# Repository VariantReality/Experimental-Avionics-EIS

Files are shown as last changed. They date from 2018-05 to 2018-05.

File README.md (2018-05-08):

# Experimental-Avionics-EIS

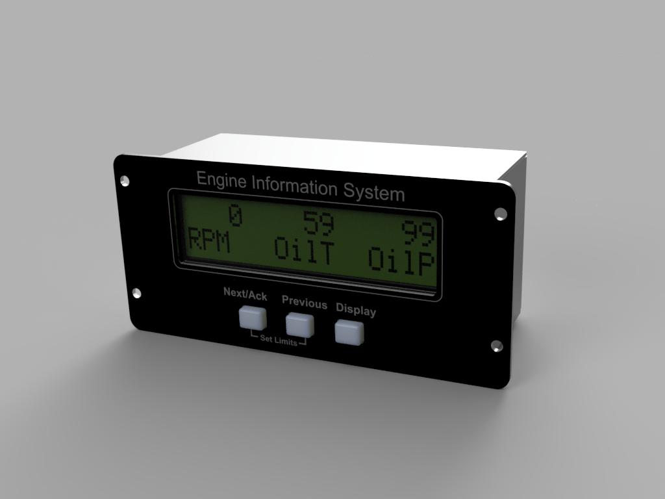
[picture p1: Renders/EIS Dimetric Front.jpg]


## Contact Information
https://hackaday.io/jomega

## Description
In an effort to bring homebuilt avionics to the experimental aircraft community, I have created a set of plans for a homebuilt aircraft engine monitor.  The processor system is based on the same technology found in the Arduino board, allowing the builder to easily add custom firmware. All of the mechanical parts can be sent to hobbyist-friendly fabrication services at reasonable costs or built at home. Since the mechanical dimensions are provided, the builder can also design a custom case. 

The features of the engine monitor include:

- EGT (x6)
- CHT (x6)
- Oil Temperature
- Oil Pressure
- Coolant Temperature
- Carb Temperature
- Outside Air Temperature (OAT)
- Tachometer input (x2) (configurable for both inductive and open/collector)
- Fuel flow (x2 for supply/return)
- 6 analog auxiliary inputs
- Flight timer
- Tach time
- Serial data output
- Backlight brightness control
- Warning light with configurable limits
- User definable pages (x4)
- Onboard memory

This repository includes all of the information you need to build the EIS yourself including:

 - Schematics
 - Mechanical CAD files
 - Firmware source code
 - Bill of Materials

The cost to buy the components and fabricate the enclosure comes to approximately $250 if you use the recommended vendors.

## Required Tools

### Software:
- Autodesk Fusion 360 (Free Enthusiast license)
- Altium Circuit maker
- Front Panel Designer
- Inkscape
- Atmel Studio

### Hardware:
- Waveshare AVR programmer or Atmel ICE programmer (most other programmer options do not work correctly with the ATMega 2560)
- RS-232 to USB converter
- Hakko soldering iron
- Sparkfun hot air gun
- AMScope
- Soldering vise + base
- Multimeter
- Tweezers
- Solder
- Solder wick
- Flux

## Recommended vendors
- [Front panel express](https://www.frontpanelexpress.com/) (CNC and digital printing)
- [Par-metal](http://www.par-metal.com/) (Sheet metal work)
- [Shapeways](https://www.shapeways.com/) (3D printing)
- [Digikey](https://www.digikey.com/) (Electronic components)

## Construction Steps

1. Modify the faceplate graphic as desired and then order all of the parts listed above
2. When the buttons and button guide arrive, they will require some cleanup. This can be done by sanding the edges where they touch the button guide or by forcing them into the button guide and then repeatedly cycling them back and forth.
3. Assemble the PCB. I would highly recommend doing this in stages and verifying functionality after each stage.
     1. Power supply circuit (verify power LED turns on)
     2. ATMega2560 circuit (verify that Atmel Studio can query the ATMega's ID)
     3. Warning light (verify that the ATMega can toggle the warning light)
     4. DSub connectors
     5. RS-232 circuit (verify that the ATMega can send data to a computer)
     6. FRAM circuit (verify that the flash IC info can be queried)
     7. ADC circuit (verify that the ADC correctly reads the input voltage)
     8. Amplifier/multiplexer circuit (verify that the ADC measures different values when the multiplexer is changed)
     9. Tach/fuel flow circuits (verify that an interrupt is triggered when a voltage is applied to the tach pins)
     10. Button board (verify that the ATMega can read each button)
     11. LCD Screen (verify that the ATMega can print to the display)
4. Assemble the button PCB
5. Program the ATMega with the EIS firmware
6. Place the button guide and buttons in place on the front panel. Place the button PCB on top and use two 4-40 locknuts to secure it in place
7. Attach the LCD to the front panel using  four 4-40 by 1.5" standoffs threaded on one side. 
8. Place the engine monitor board on top of the standoffs and secure with two 4-40 by 7/32 standoffs on the bottom and two 4-40 screw on the top.
9. Place the rear enclosure over the top (it should be a snug fit). Secure using two 4-40 screws.

## Additional Photos



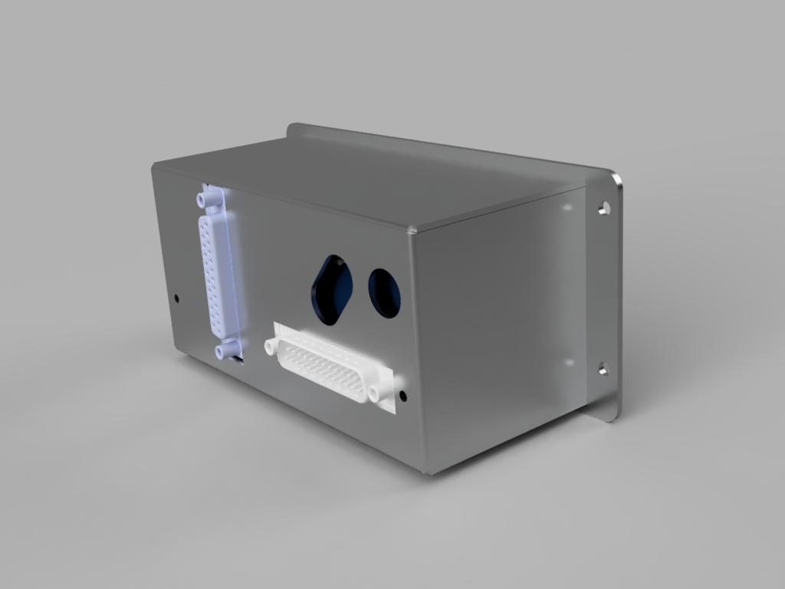
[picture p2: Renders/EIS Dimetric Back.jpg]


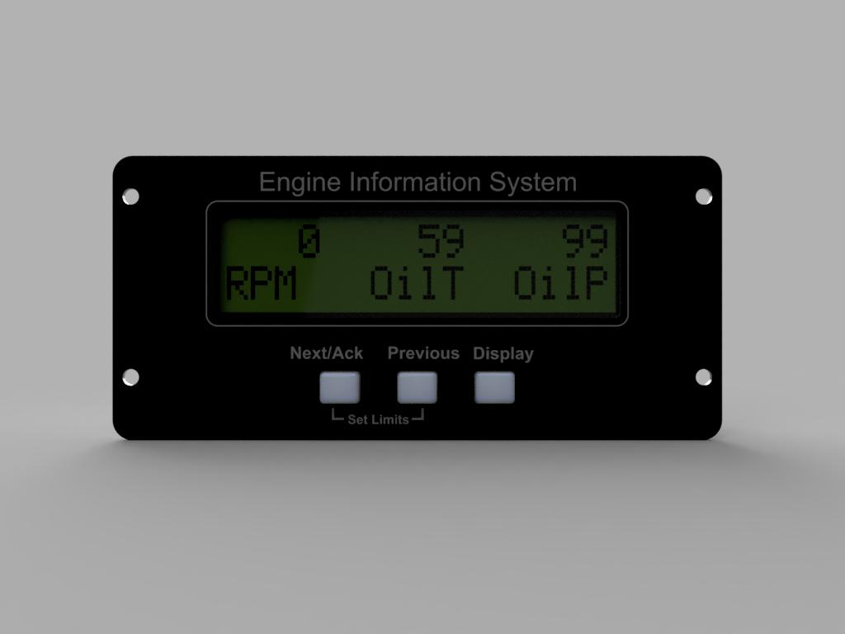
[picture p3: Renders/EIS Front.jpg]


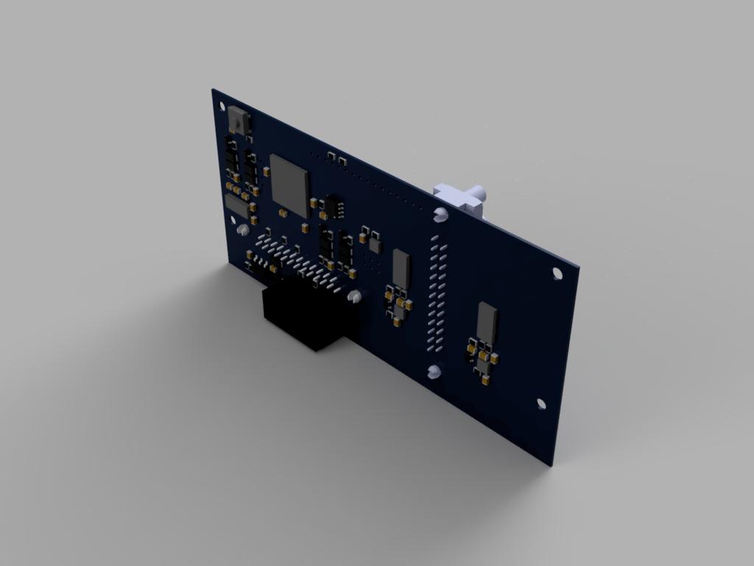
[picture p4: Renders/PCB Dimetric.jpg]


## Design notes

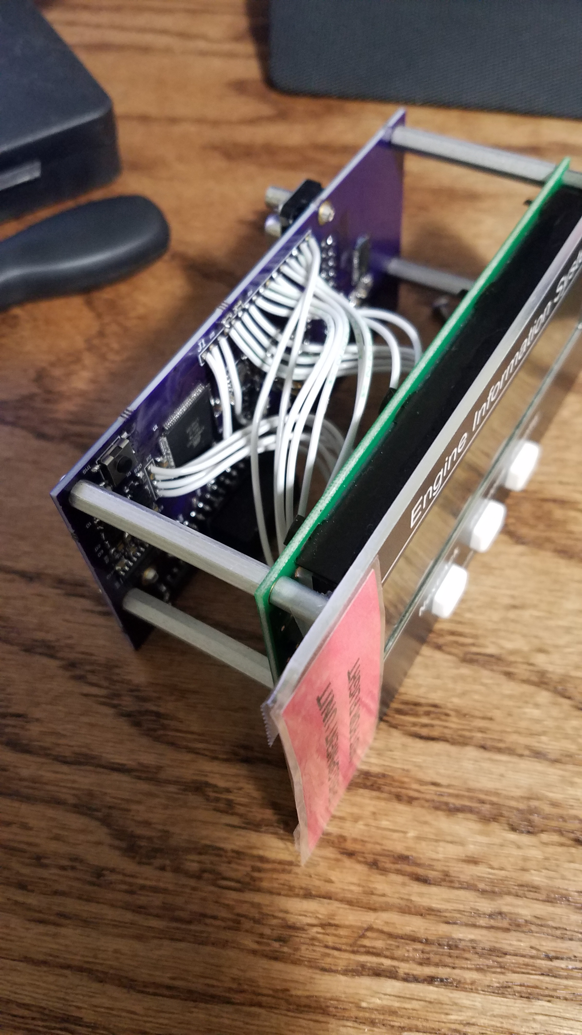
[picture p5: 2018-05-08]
Photos/Inside.jpg

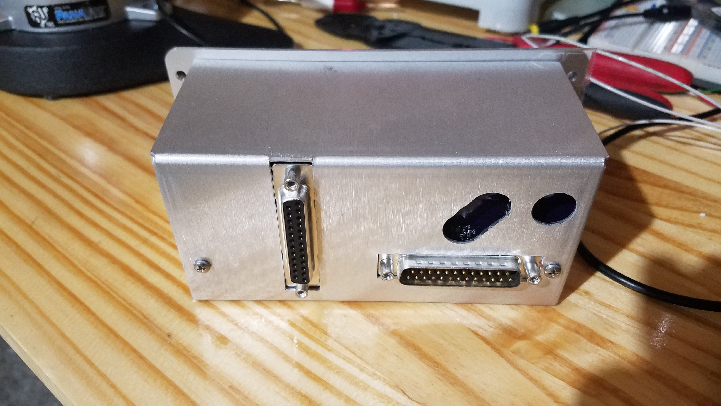
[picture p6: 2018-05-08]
Photos/Back.jpg

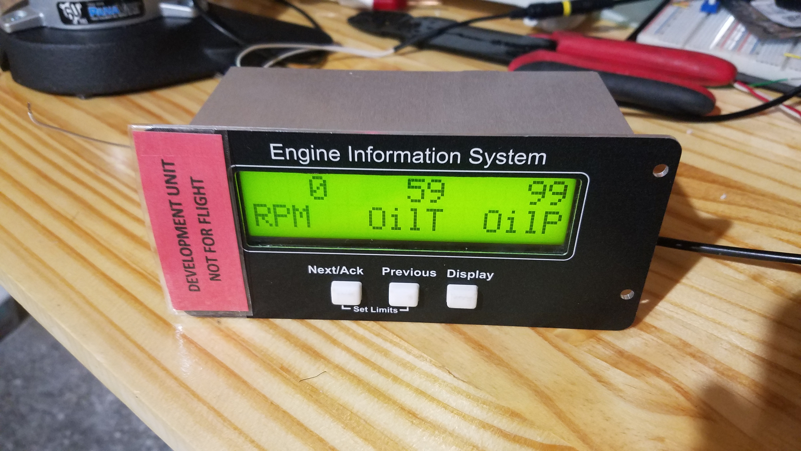
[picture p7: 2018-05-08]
Photos/Front.jpg

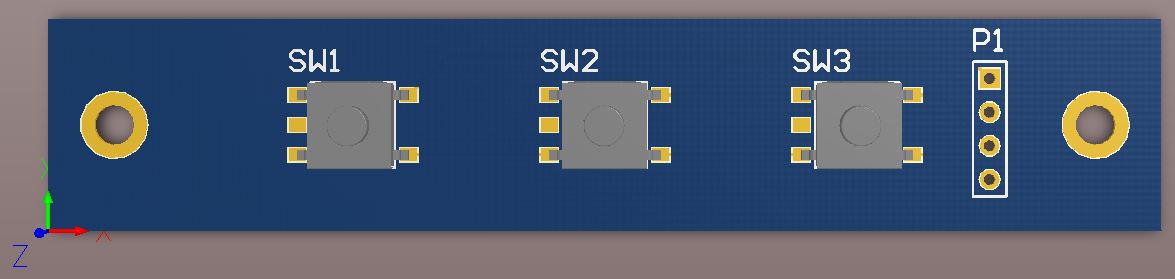
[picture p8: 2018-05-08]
Renders/Button PCB.JPG

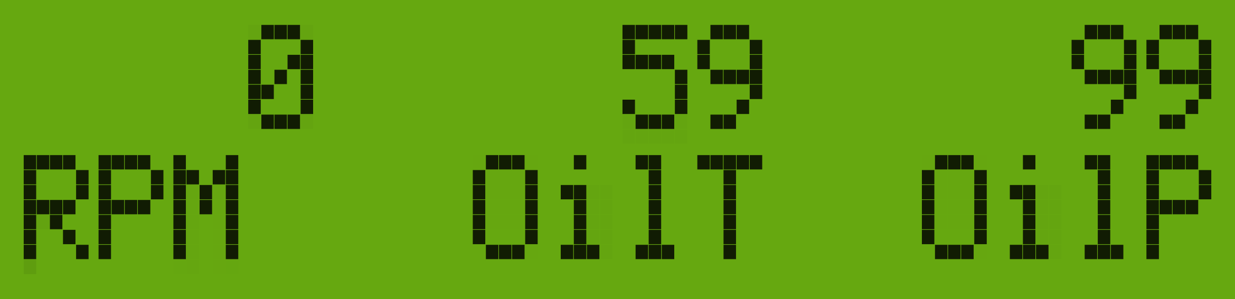
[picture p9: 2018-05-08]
Graphics/LCD Screen home.png

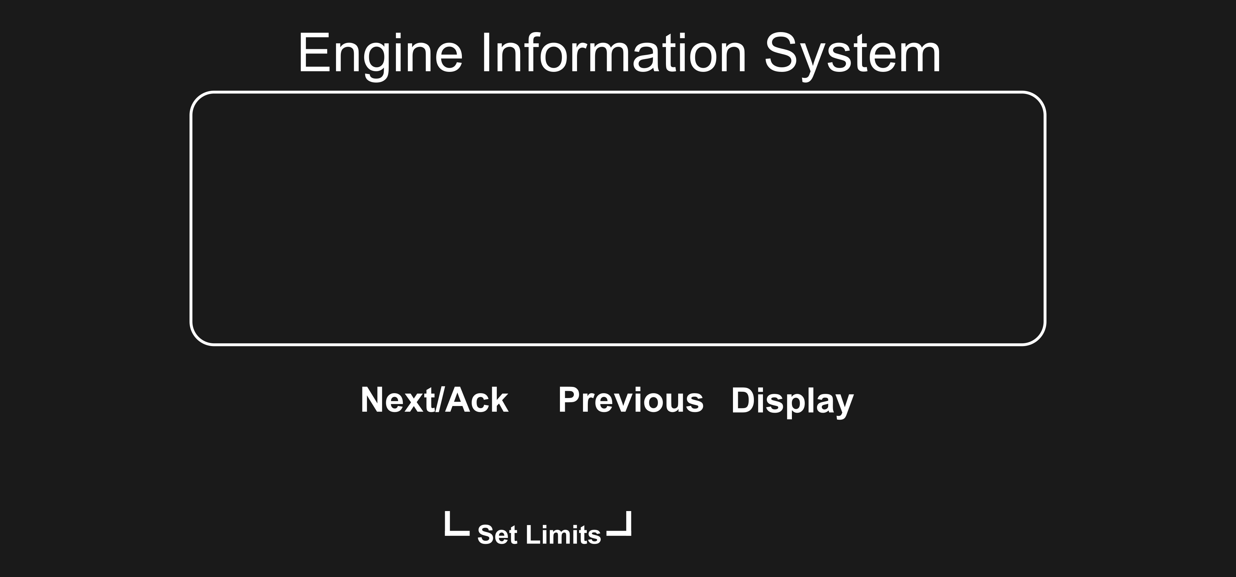
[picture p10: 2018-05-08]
Graphics/Panel Graphics.png

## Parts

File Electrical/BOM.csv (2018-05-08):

Quantity | Part Number | Description
1 | FW1600008CT-ND | 16 MHz Crystal
1 | 296-13094-1-ND | MAX3232
2 | ADG707BRUZ-ND | ADG707
1 | 811-3085-ND | NCS3S1203SC
1 | AD8494ARMZ-ND | AD8494
1 | AD8495ARMZ-ND | AD8495
1 | 296-38850-1-ND | ADS1118
1 | 296-44517-1-ND | LM7805MP
1 | 865-1260-1-ND | MB85R64 Memory
1 | ATMEGA2560-16AU-ND | ATMega 2560
4 | CKN10813CT-ND | PTS641
1 | x | 4x1 Header
1 | 609-3234-ND | 3x2 Header
1 | x | 16x1 Header
1 | 609-1509-ND | DB25 Female
1 | 609-1503-ND | DB25 Male
1 | 1727-4436-1-ND | TVS
1 | 754-1438-1-ND | LED (Green)
1 | 754-1791-1-ND | LED (Red)
4 | DB2440100LCT-ND | Schottky Diode
4 | PDZVTR4.3BCT-ND | Zener Diode
1 | 1727-1730-1-ND | Diode
4 | 497-12132-1-ND | BAT54S
2 | 296-17685-1-ND | TLVH431
2 | IRLML0030TRPBFCT-ND | IRLML0030TRPbF
15 | 490-8051-1-ND | Capacitor (0805) 0.1uF
5 | 490-6060-1-ND | Capacitor (0805) 0.01uF
4 | 1276-1260-1-ND | Capacitor (0805) 3.3nF
3 | 399-1113-1-ND | Capacitor (0805) 22pF
1 | 587-1287-1-ND | Capacitor (0805) 0.22uF
3 | P1MDACT-ND | Resistor (0805) 1M
4 | 311-470KCRCT-ND | Resistor (0805) 470k
4 | 311-220KCRCT-ND | Resistor (0805) 220k
9 | 311-10.0KCRCT-ND | Resistor (0805) 10k
1 | 311-9.10KCRCT-ND | Resistor (0805) 9k
1 | 311-2.00KCRCT-ND | Resistor (0805) 2k
3 | 311-1.00KCRCT-ND | Resistor (0805) 1k
7 | 311-300CRCT-ND | Resistor (0805) 300
6 | 311-100CRCT-ND | Resistor (0805) 100
1 | 311-27.0CRCT-ND | Resistor (0805) 27

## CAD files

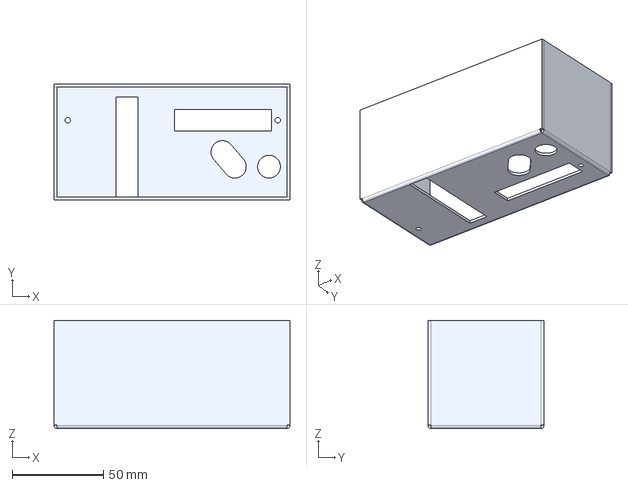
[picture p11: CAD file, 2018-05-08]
Mechanical/Back Enclosure.step
129.2 x 63.4 x 59.3 mm

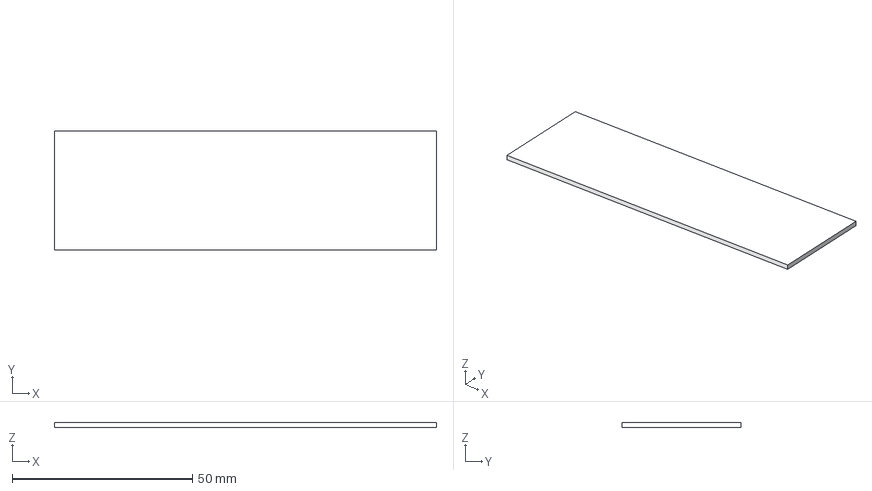
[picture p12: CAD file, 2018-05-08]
Mechanical/Glass Cover.step
106.0 x 33.0 x 1.50 mm

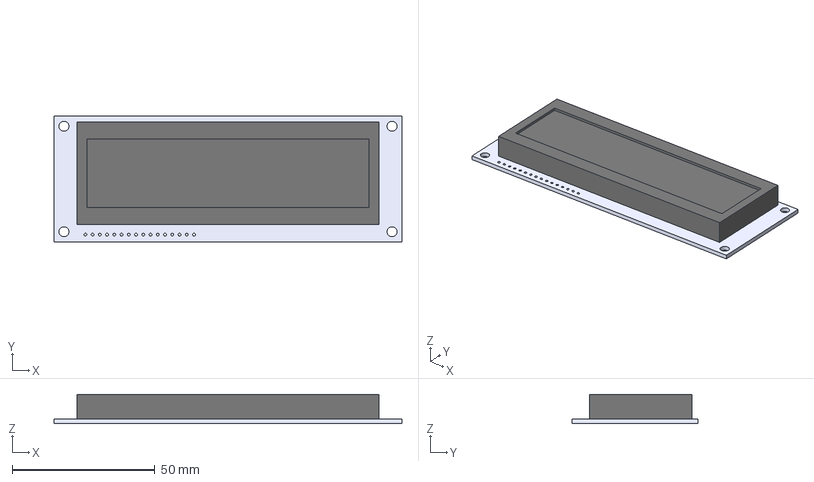
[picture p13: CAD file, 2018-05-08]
Mechanical/LCD Screen.step
122.0 x 44.0 x 10.2 mm

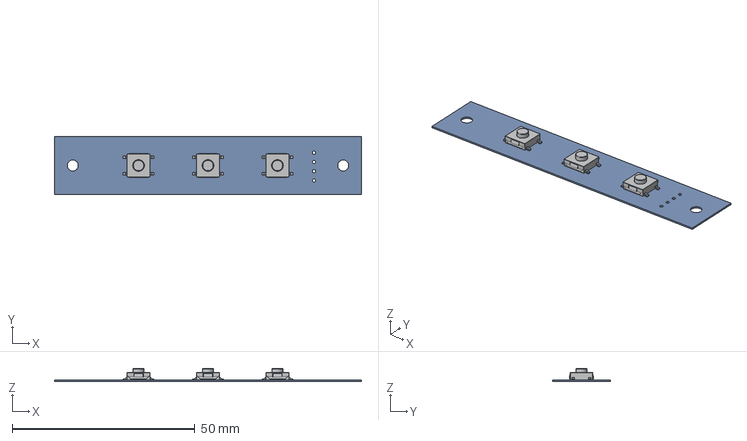
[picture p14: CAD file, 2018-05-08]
Mechanical/button_board.step
84.0 x 16.0 x 3.51 mm

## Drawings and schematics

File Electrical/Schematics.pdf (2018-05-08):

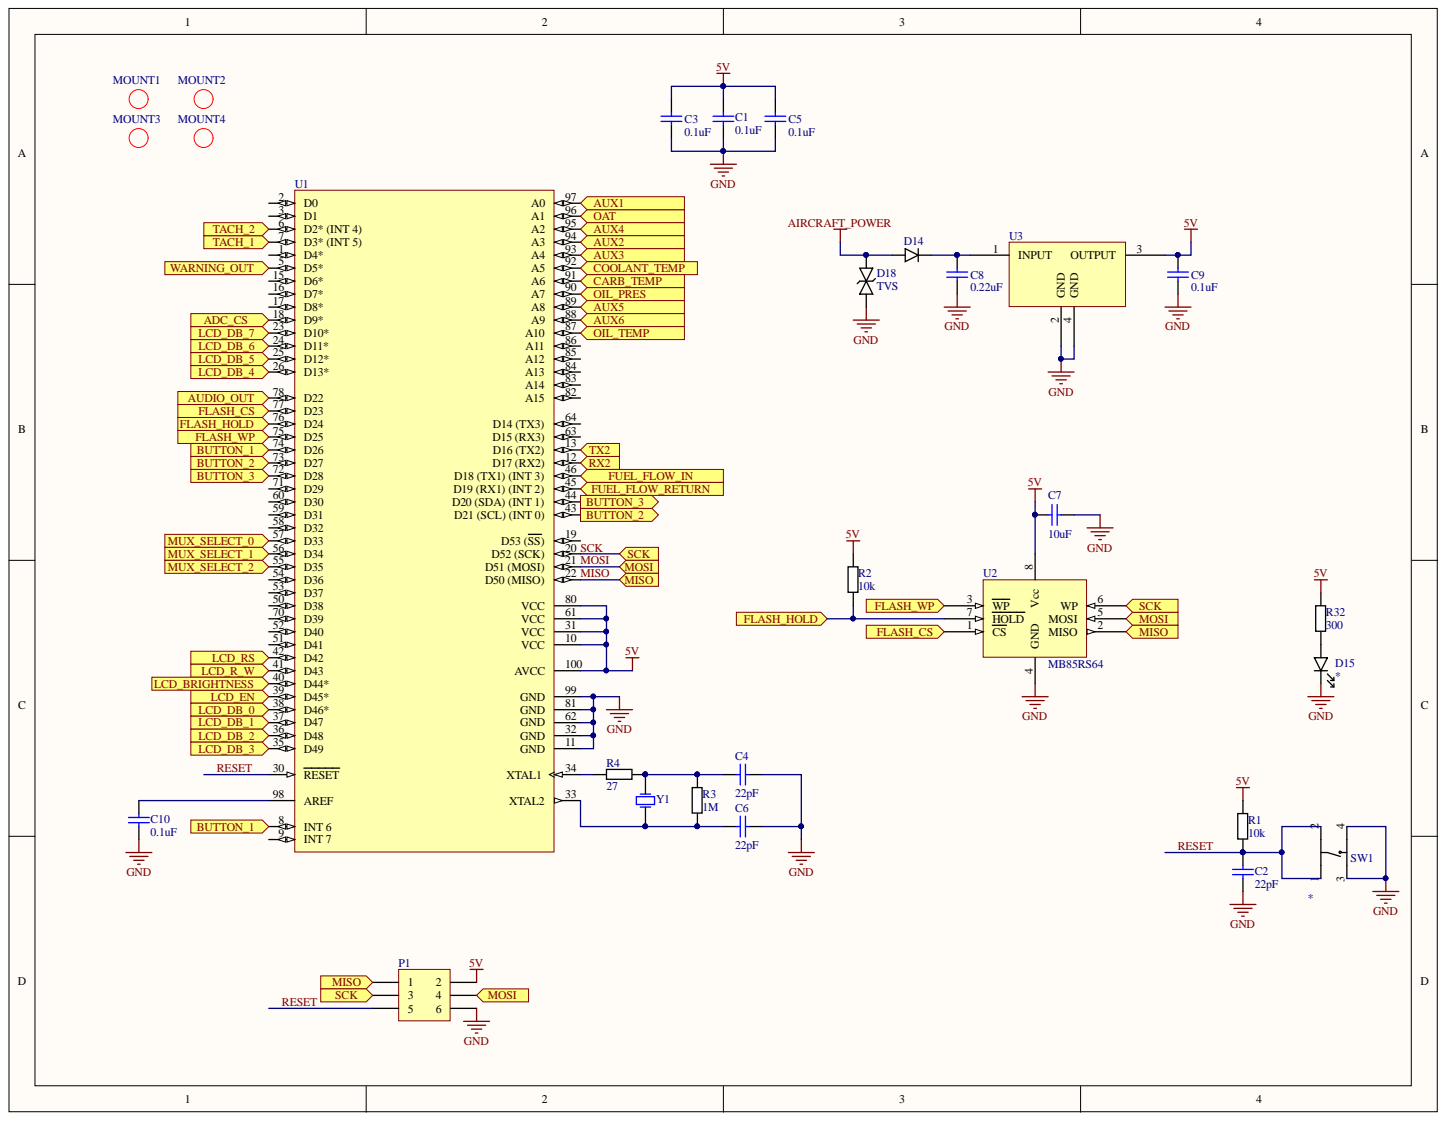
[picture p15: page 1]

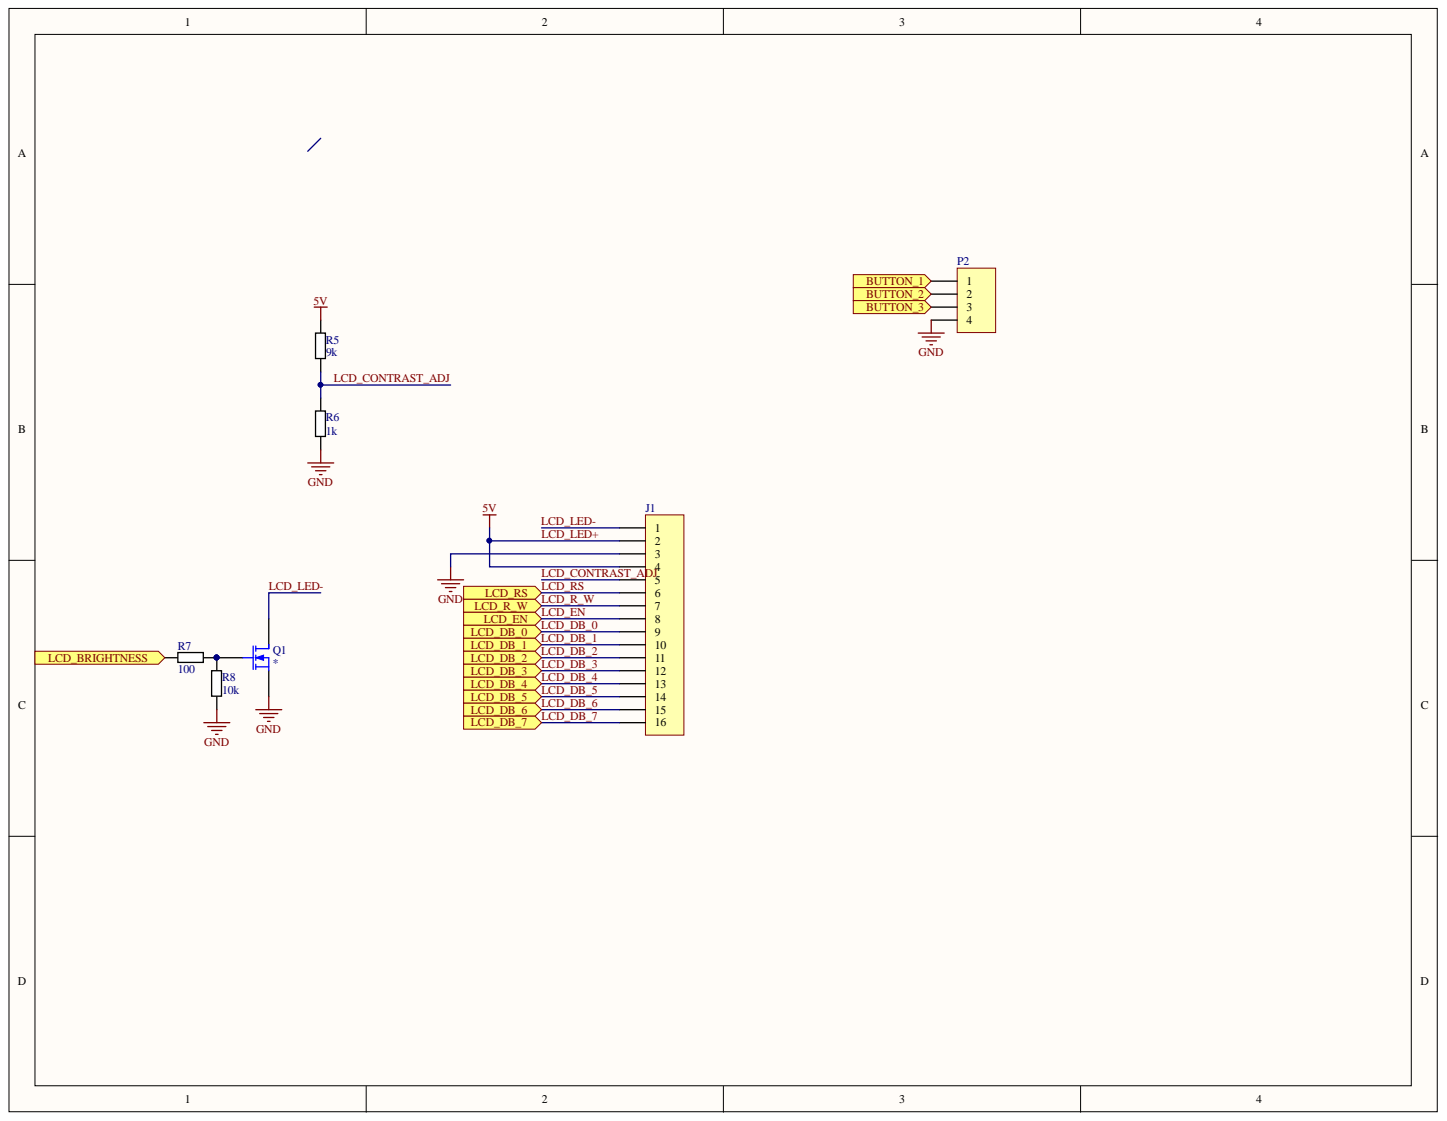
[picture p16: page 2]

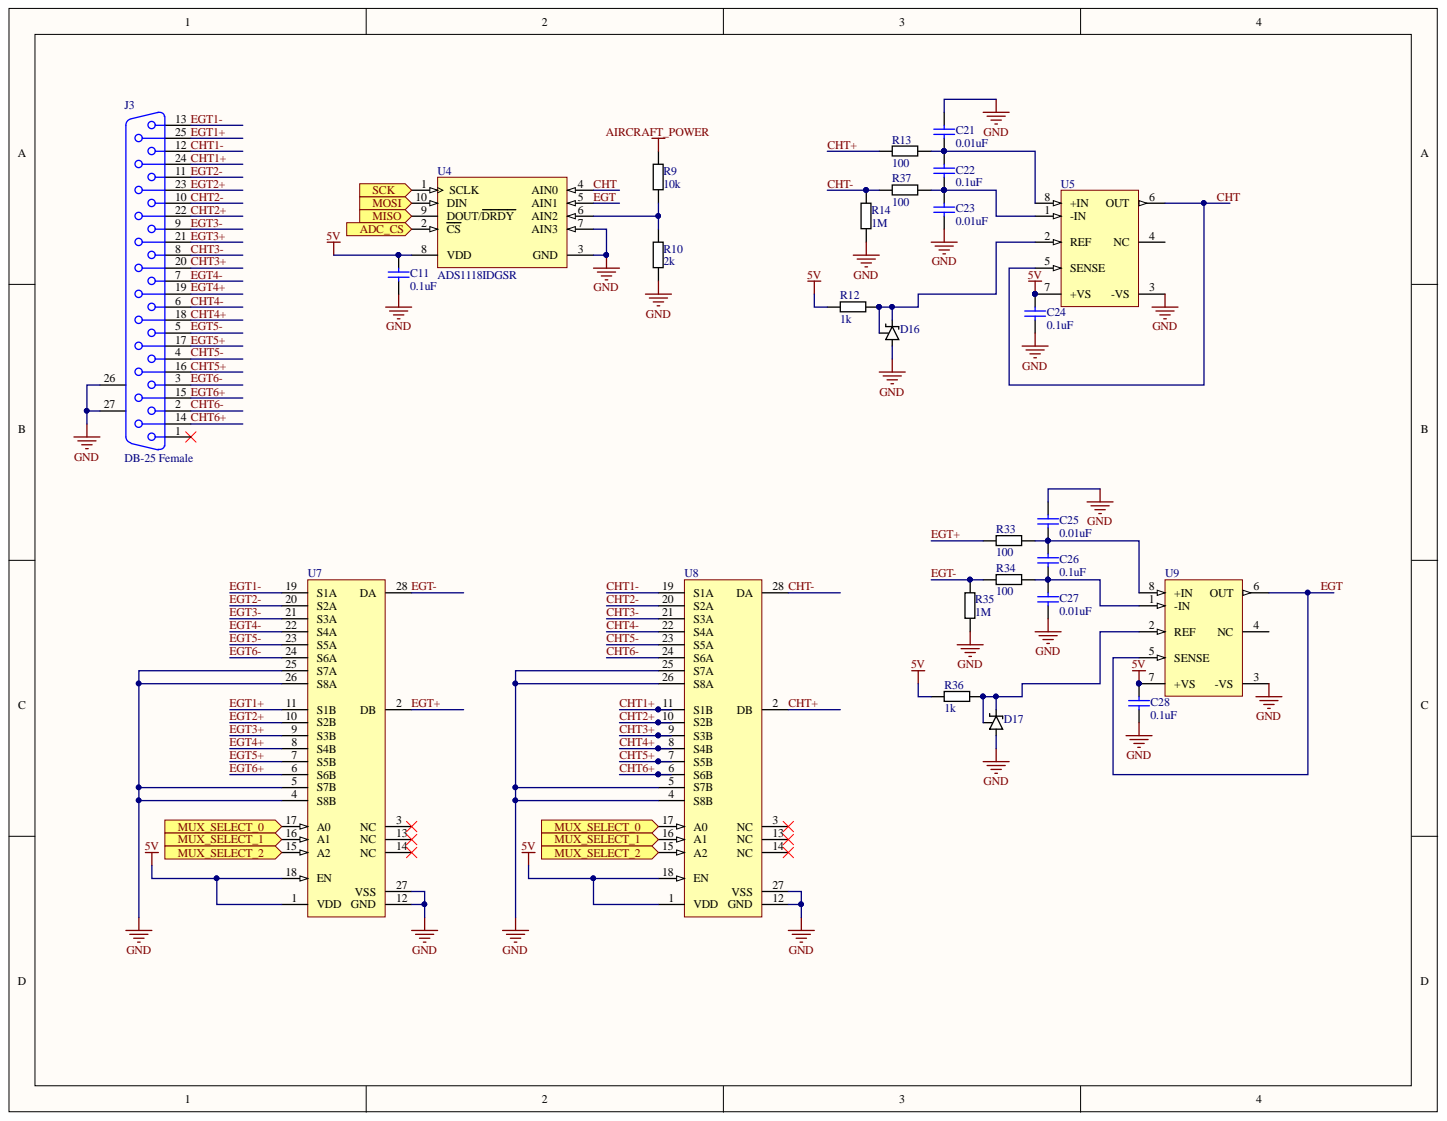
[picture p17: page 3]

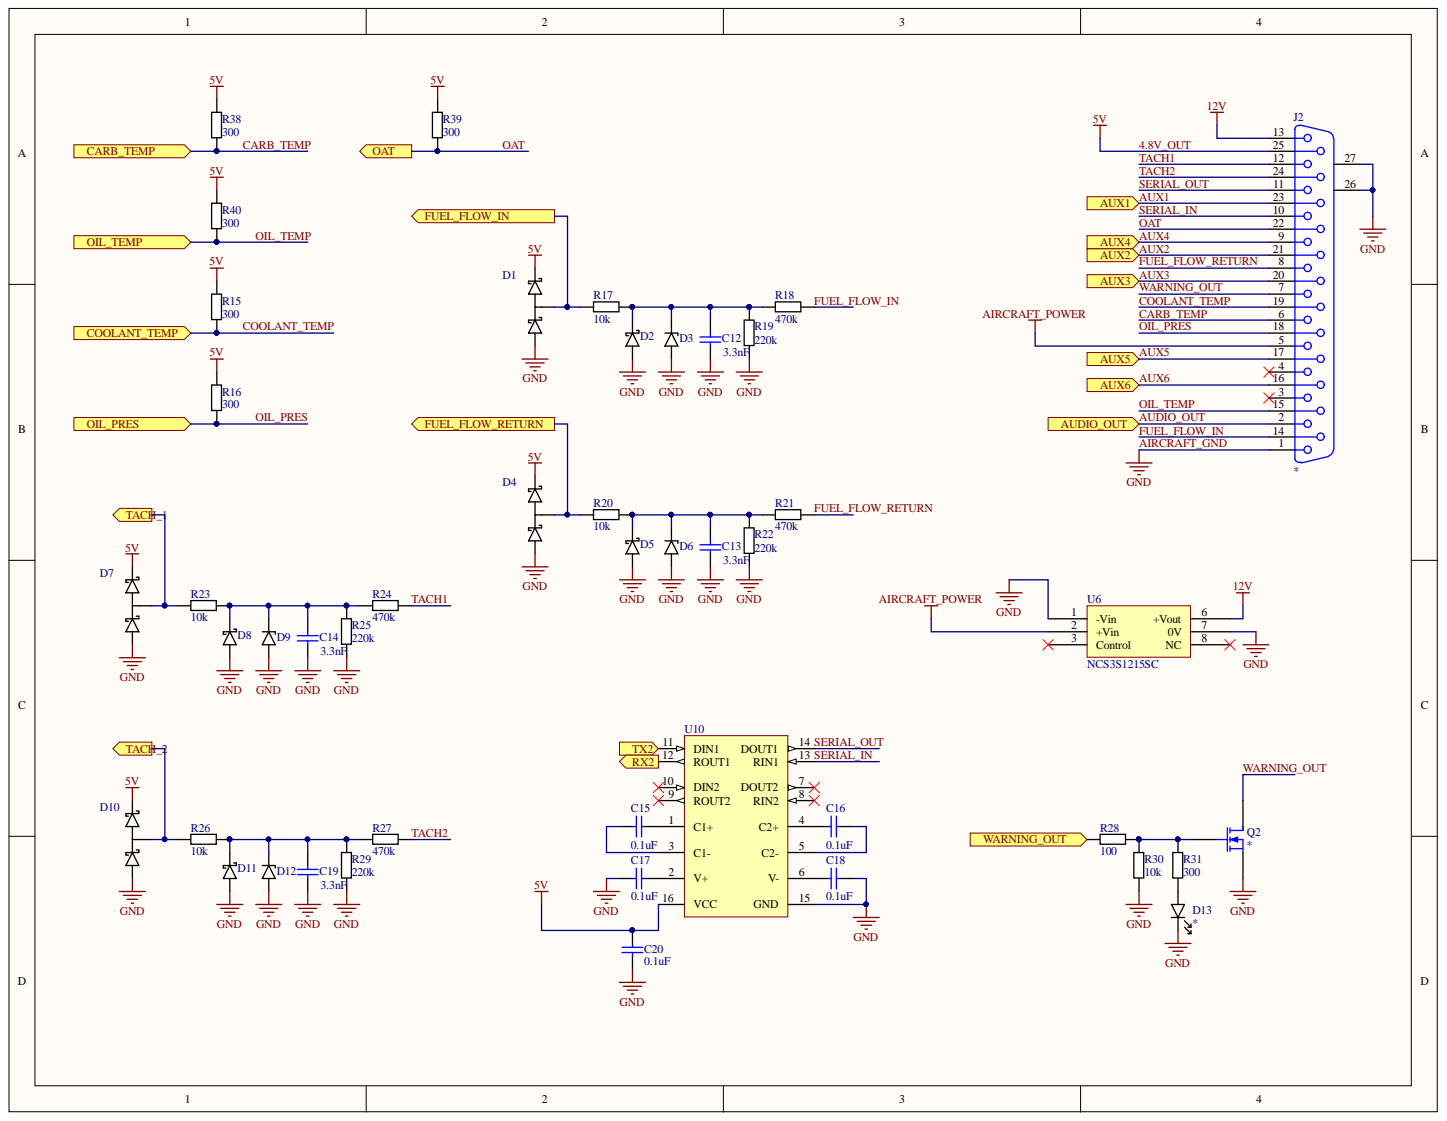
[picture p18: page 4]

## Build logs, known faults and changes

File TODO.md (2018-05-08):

#### List of tasks that need to be completed before the EFIS is flight-worthy

- [ ] Add debouncing circuit to button board
- [ ] Add pullup resistor to ADS1118 CS line
- [ ] Add pullup resistor to thermocouple inputs to prevent floating while unconnected
- [ ] Remove R3 and R4
- [ ] Remove tach input voltage divider and replace with series 1k
- [ ] Change Vref on EGT sensor

#### List of tasks that would be nice but not necessary

- [ ] Flip LCD connector to align with LCD board.
- [ ] Move serial to port 1 for better arduino compatability
- [ ] Add FPC screen interconnect
- [ ] Replace crystal with larger form factor for ease of assembly
- [ ] Remove extra pad on reset button
- [ ] Make tach circuit compatible with open-collector sensors (Lycoming)
- [ ] Move transistor from underneath DSUB

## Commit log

2018-05-08 Added additional files
    [Back Enclosure.step, Glass Cover.step, LCD Screen.step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]
2018-05-08 Added BOM
    [BOM.csv]
2018-05-08 Added sensor information
